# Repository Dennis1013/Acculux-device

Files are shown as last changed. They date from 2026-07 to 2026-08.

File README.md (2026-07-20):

# Acculux-device
**Capstone Project: Development of a Pressure and Navigation System For Nirscan Probe for Breast Cancer Detection**

The objective of this project is to add functionality to the existing NIR Imaging Inc. device in the way of:
 - Orientation tracking
 - Positional tracking
 - Force sensing

Download the latest software release here: https://github.com/jjhcwoo/Acculux-device/releases/latest

## Members

Justin Woo 

Allan Chang

Aodren Auffrédou-Heinicke

Dennis Huang

Nathan Cushing

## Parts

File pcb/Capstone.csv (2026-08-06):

Designator | Comment | Footprint | JLCPCB Part #
C1,C2 | 10u | Capacitor_SMD:C_0603_1608Metric
C5,C6,C7,C8,C10,C12,C13,C14,C15,C16,C18,C19,C20,C22,C23,C24,C26,C27,C28,C30,C34 | 0.1u | Capacitor_SMD:C_0603_1608Metric
C9 | 22u | Capacitor_SMD:C_0603_1608Metric
C11 | 1u | Capacitor_SMD:C_0603_1608Metric
C17,C21,C25,C29 | 47n | Capacitor_SMD:C_0603_1608Metric
C31,C35 | 2.2u +/- 10% X7R | Capacitor_SMD:C_0603_1608Metric
C32,C33 | 10n +/- 10% X7R | Capacitor_SMD:C_0603_1608Metric
C43,C44 | 10n | Capacitor_SMD:C_0603_1608Metric
D1 | D_Schottky BAT760 | Diode_SMD:D_SOD-323F
D2 | LED (RED) | LED_SMD:LED_0603_1608Metric
D3 | LED (AMBER) | LED_SMD:LED_0603_1608Metric
IC1,IC2,IC3,IC4 | HSFPAR004A | HSFPAR004A:HSFPAR004A | C470800
J1,J2,J3,J4 | Conn_01x01 | MountingHole:MountingHole_3.2mm_M3_DIN965_Pad
J5 | Conn_01x02 | Connector_PinHeader_2.54mm:PinHeader_1x04_P2.54mm_Horizontal
J6 | USB_C_Receptacle | Connector_USB:USB_C_Receptacle_GCT_USB4105-xx-A_16P_TopMnt_Horizontal
J7 | Conn_02x02_Counter_Clockwise | Connector_PinSocket_2.54mm:PinSocket_2x02_P2.54mm_Vertical
R1,R4,R9,R11,R12,R32,R33 | 10k | Resistor_SMD:R_0603_1608Metric
R2,R3 | 5.1k | Resistor_SMD:R_0603_1608Metric
R5,R16,R20,R24,R28 | 100 | Resistor_SMD:R_0603_1608Metric
R6 | 220 | Resistor_SMD:R_0603_1608Metric
R10 | 2k | Resistor_SMD:R_0603_1608Metric
R13,R17,R21,R25 | 6.49k +/- 1% | Resistor_SMD:R_0603_1608Metric
R14,R18,R22,R26 | 10k +/- 1% | Resistor_SMD:R_0603_1608Metric
R15,R19,R23,R27 | 3k +/- 1% | Resistor_SMD:R_0603_1608Metric
R36,R37,R38,R39 | 0 | Resistor_SMD:R_0603_1608Metric
SW1,SW2 | SW_Push | Button_Switch_SMD:SW_SPST_EVQP7A
U1,U7 | ADS1015IDGS | Package_SO:TSSOP-10_3x3mm_P0.5mm | C193969
U2 | ESP32-S3-WROOM-1 | RF_Module:ESP32-S3-WROOM-1 | C2913197
U3 | TLV75733PDBV | Package_TO_SOT_SMD:SOT-23-5 | C485517
U4 | USBLC6-2SC6 | Package_TO_SOT_SMD:SOT-23-6 | C7519
U6,U8,U9,U10 | INA333xxDGK | Package_SO:VSSOP-8_3x3mm_P0.65mm | C19450
U12,U13 | ICM-42688-P | ICM_42688_P:LGA14_2P5X3X0P91_TDK | C1850418

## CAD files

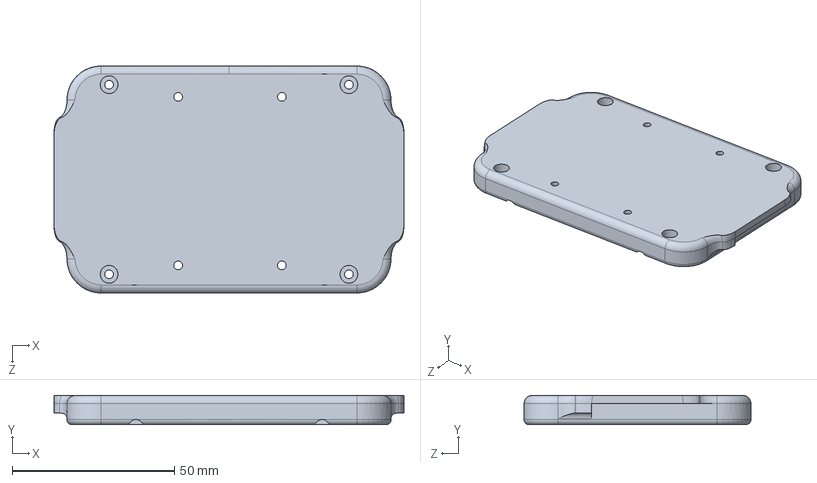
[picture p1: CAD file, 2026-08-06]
model/StampJacket.SLDPRT
108.0 x 9.00 x 70.0 mm

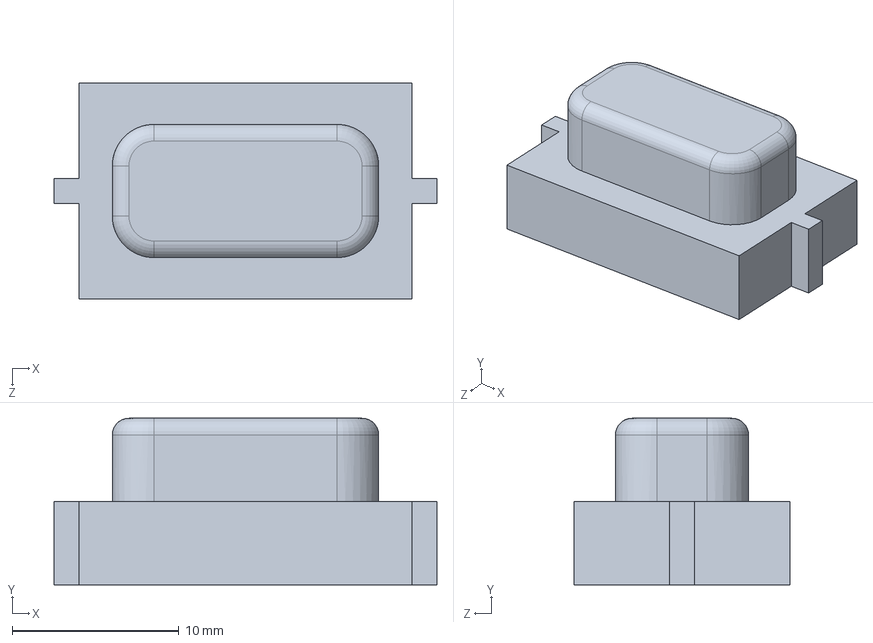
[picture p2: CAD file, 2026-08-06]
model/ScanButton.SLDPRT
23.0 x 10.0 x 13.0 mm

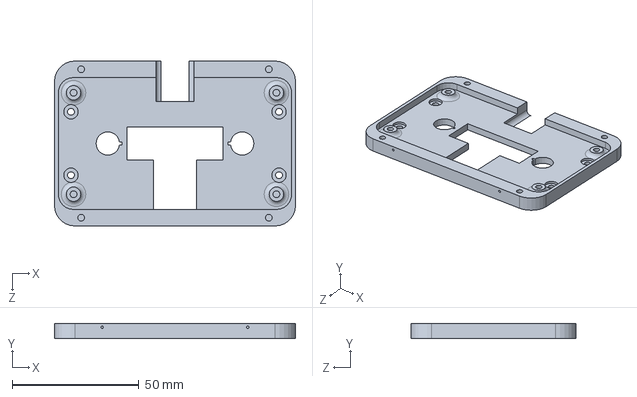
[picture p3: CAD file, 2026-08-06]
model/StampHead.SLDPRT
95.0 x 6.00 x 65.0 mm

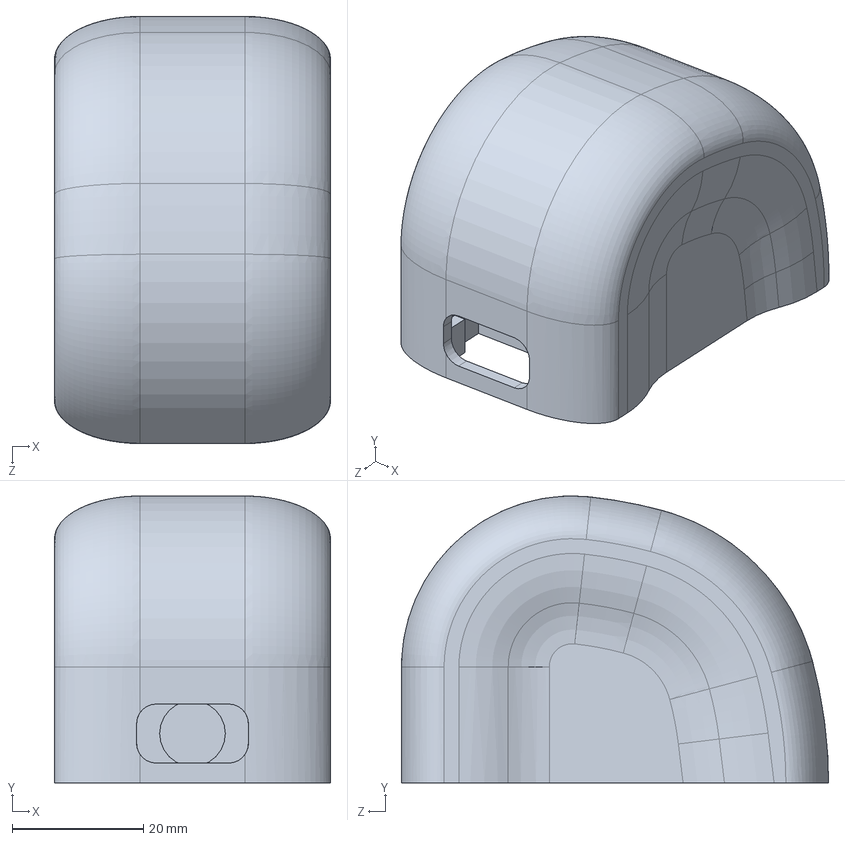
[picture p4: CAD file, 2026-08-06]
model/ErgoHandle.SLDPRT
42.0 x 43.6 x 65.0 mm

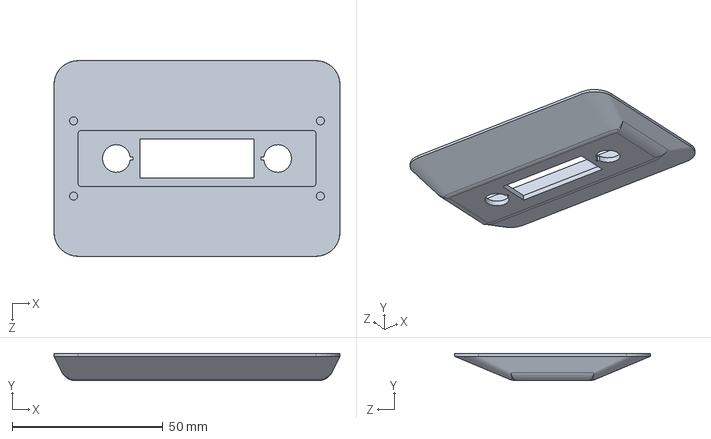
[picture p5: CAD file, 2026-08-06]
model/NIRscanhead.SLDPRT
95.0 x 9.05 x 65.0 mm

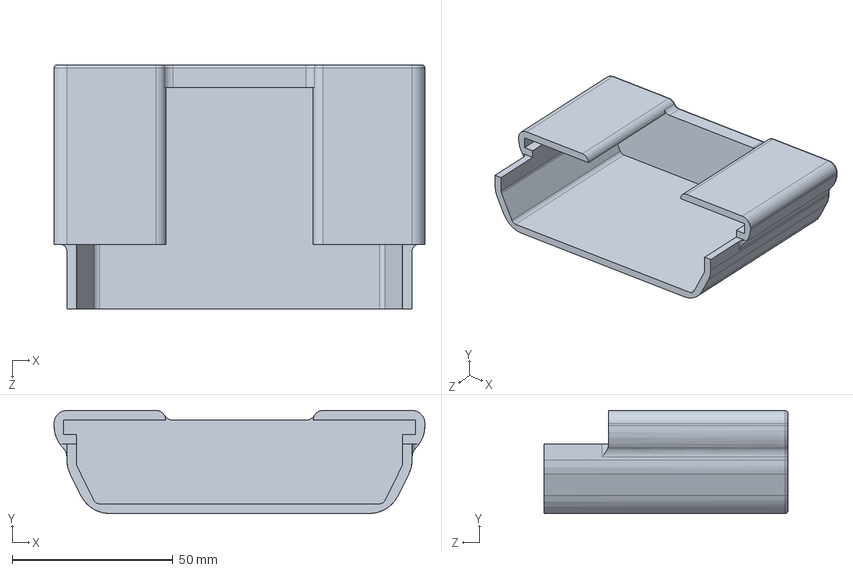
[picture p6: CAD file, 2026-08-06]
model/Cover.SLDPRT
115.4 x 32.0 x 76.0 mm

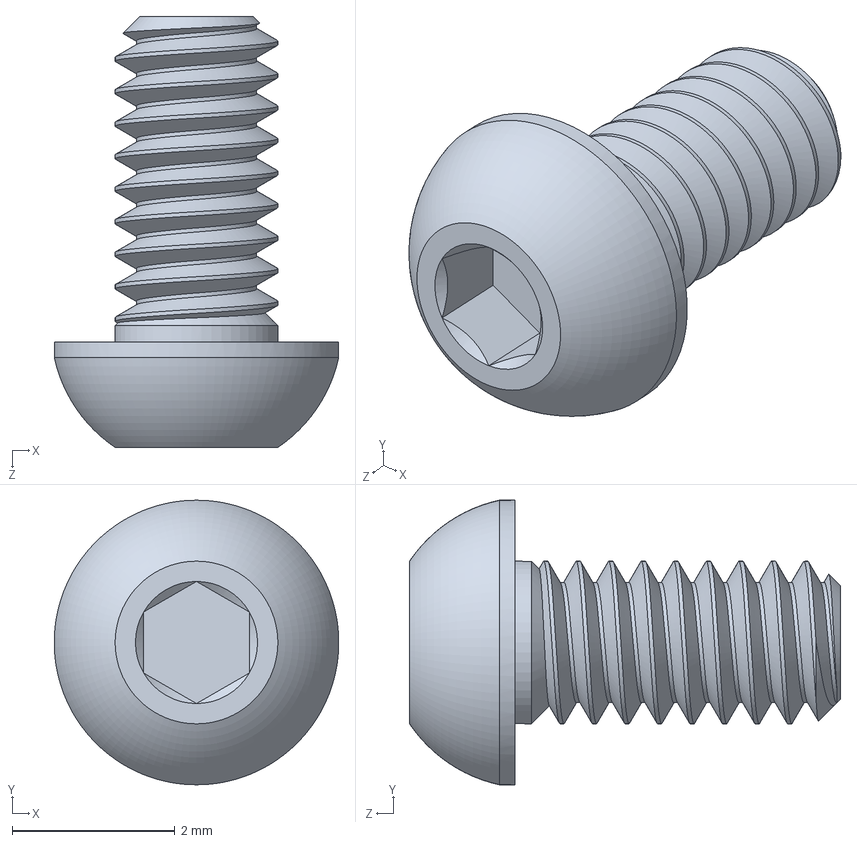
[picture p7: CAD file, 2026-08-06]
model/92095A451_18-8 Stainless Steel Button Head Hex-Drive Screw.SLDPRT
3.50 x 3.50 x 5.30 mm

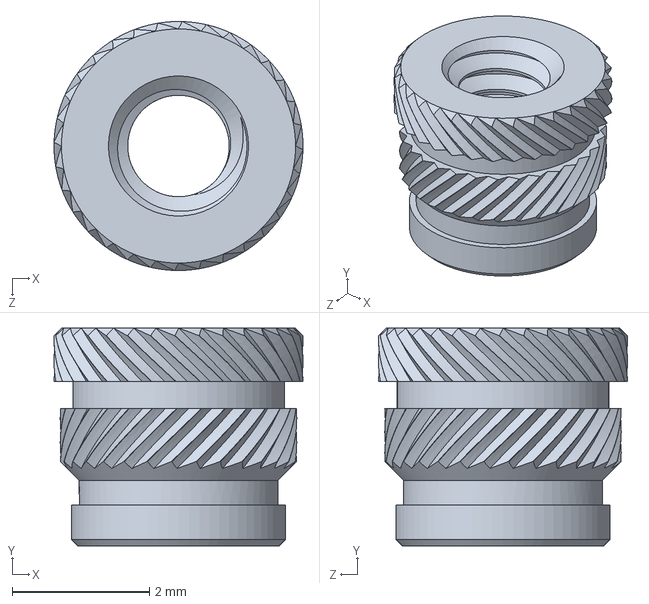
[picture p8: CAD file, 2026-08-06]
model/94459A767_Heat-Set Inserts for Plastic.SLDPRT
3.63 x 3.17 x 3.63 mm

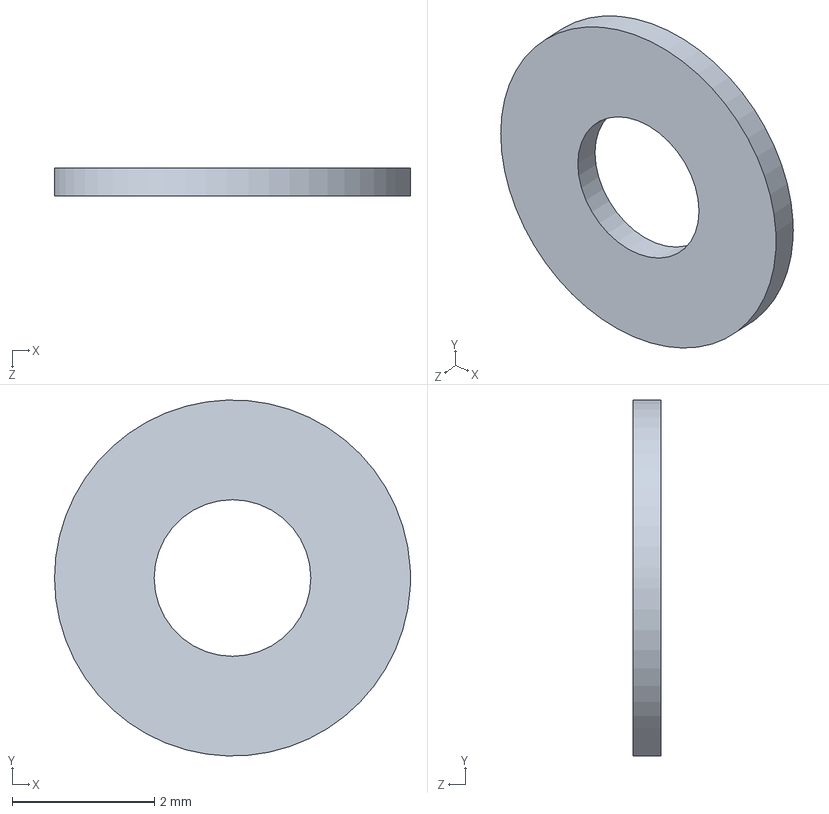
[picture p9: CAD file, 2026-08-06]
model/93475A195_18-8 Stainless Steel Washer.SLDPRT
5.00 x 5.00 x 0.4 mm

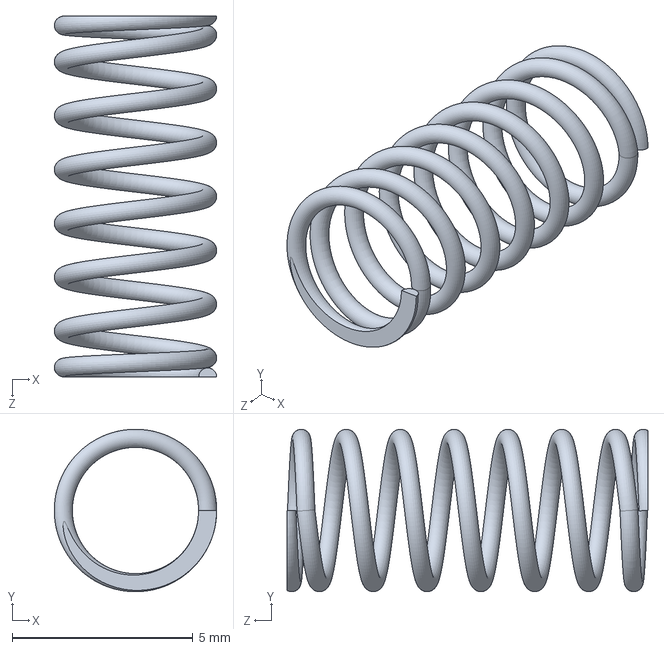
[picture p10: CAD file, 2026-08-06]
model/8969T382_316 Stainless Steel Corrosion-Resistant Compression Springs.SLDPRT
4.50 x 4.50 x 10.0 mm

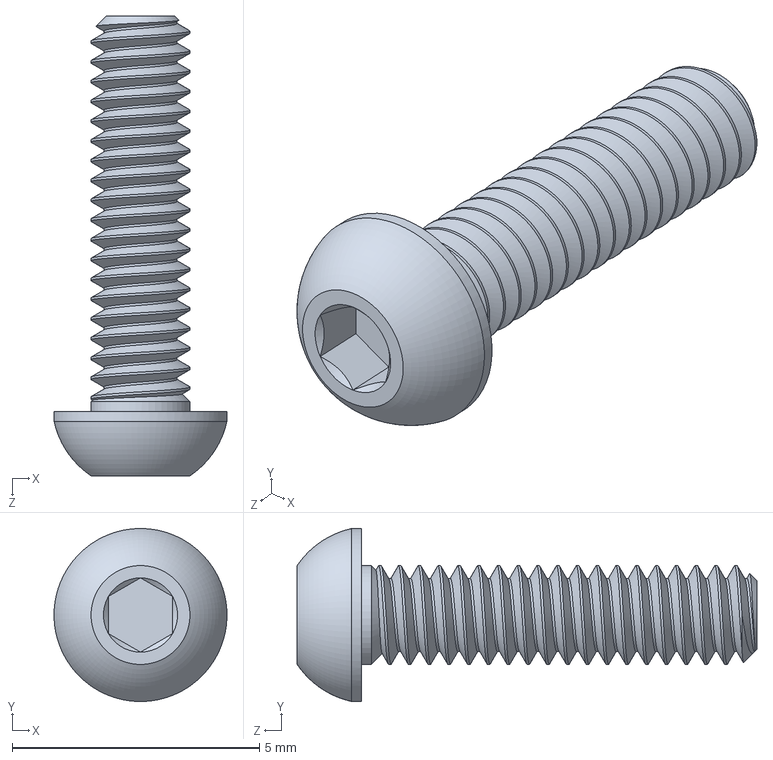
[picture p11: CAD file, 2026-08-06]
model/92095A454_18-8 Stainless Steel Button Head Hex-Drive Screw.SLDPRT
3.50 x 3.50 x 9.30 mm

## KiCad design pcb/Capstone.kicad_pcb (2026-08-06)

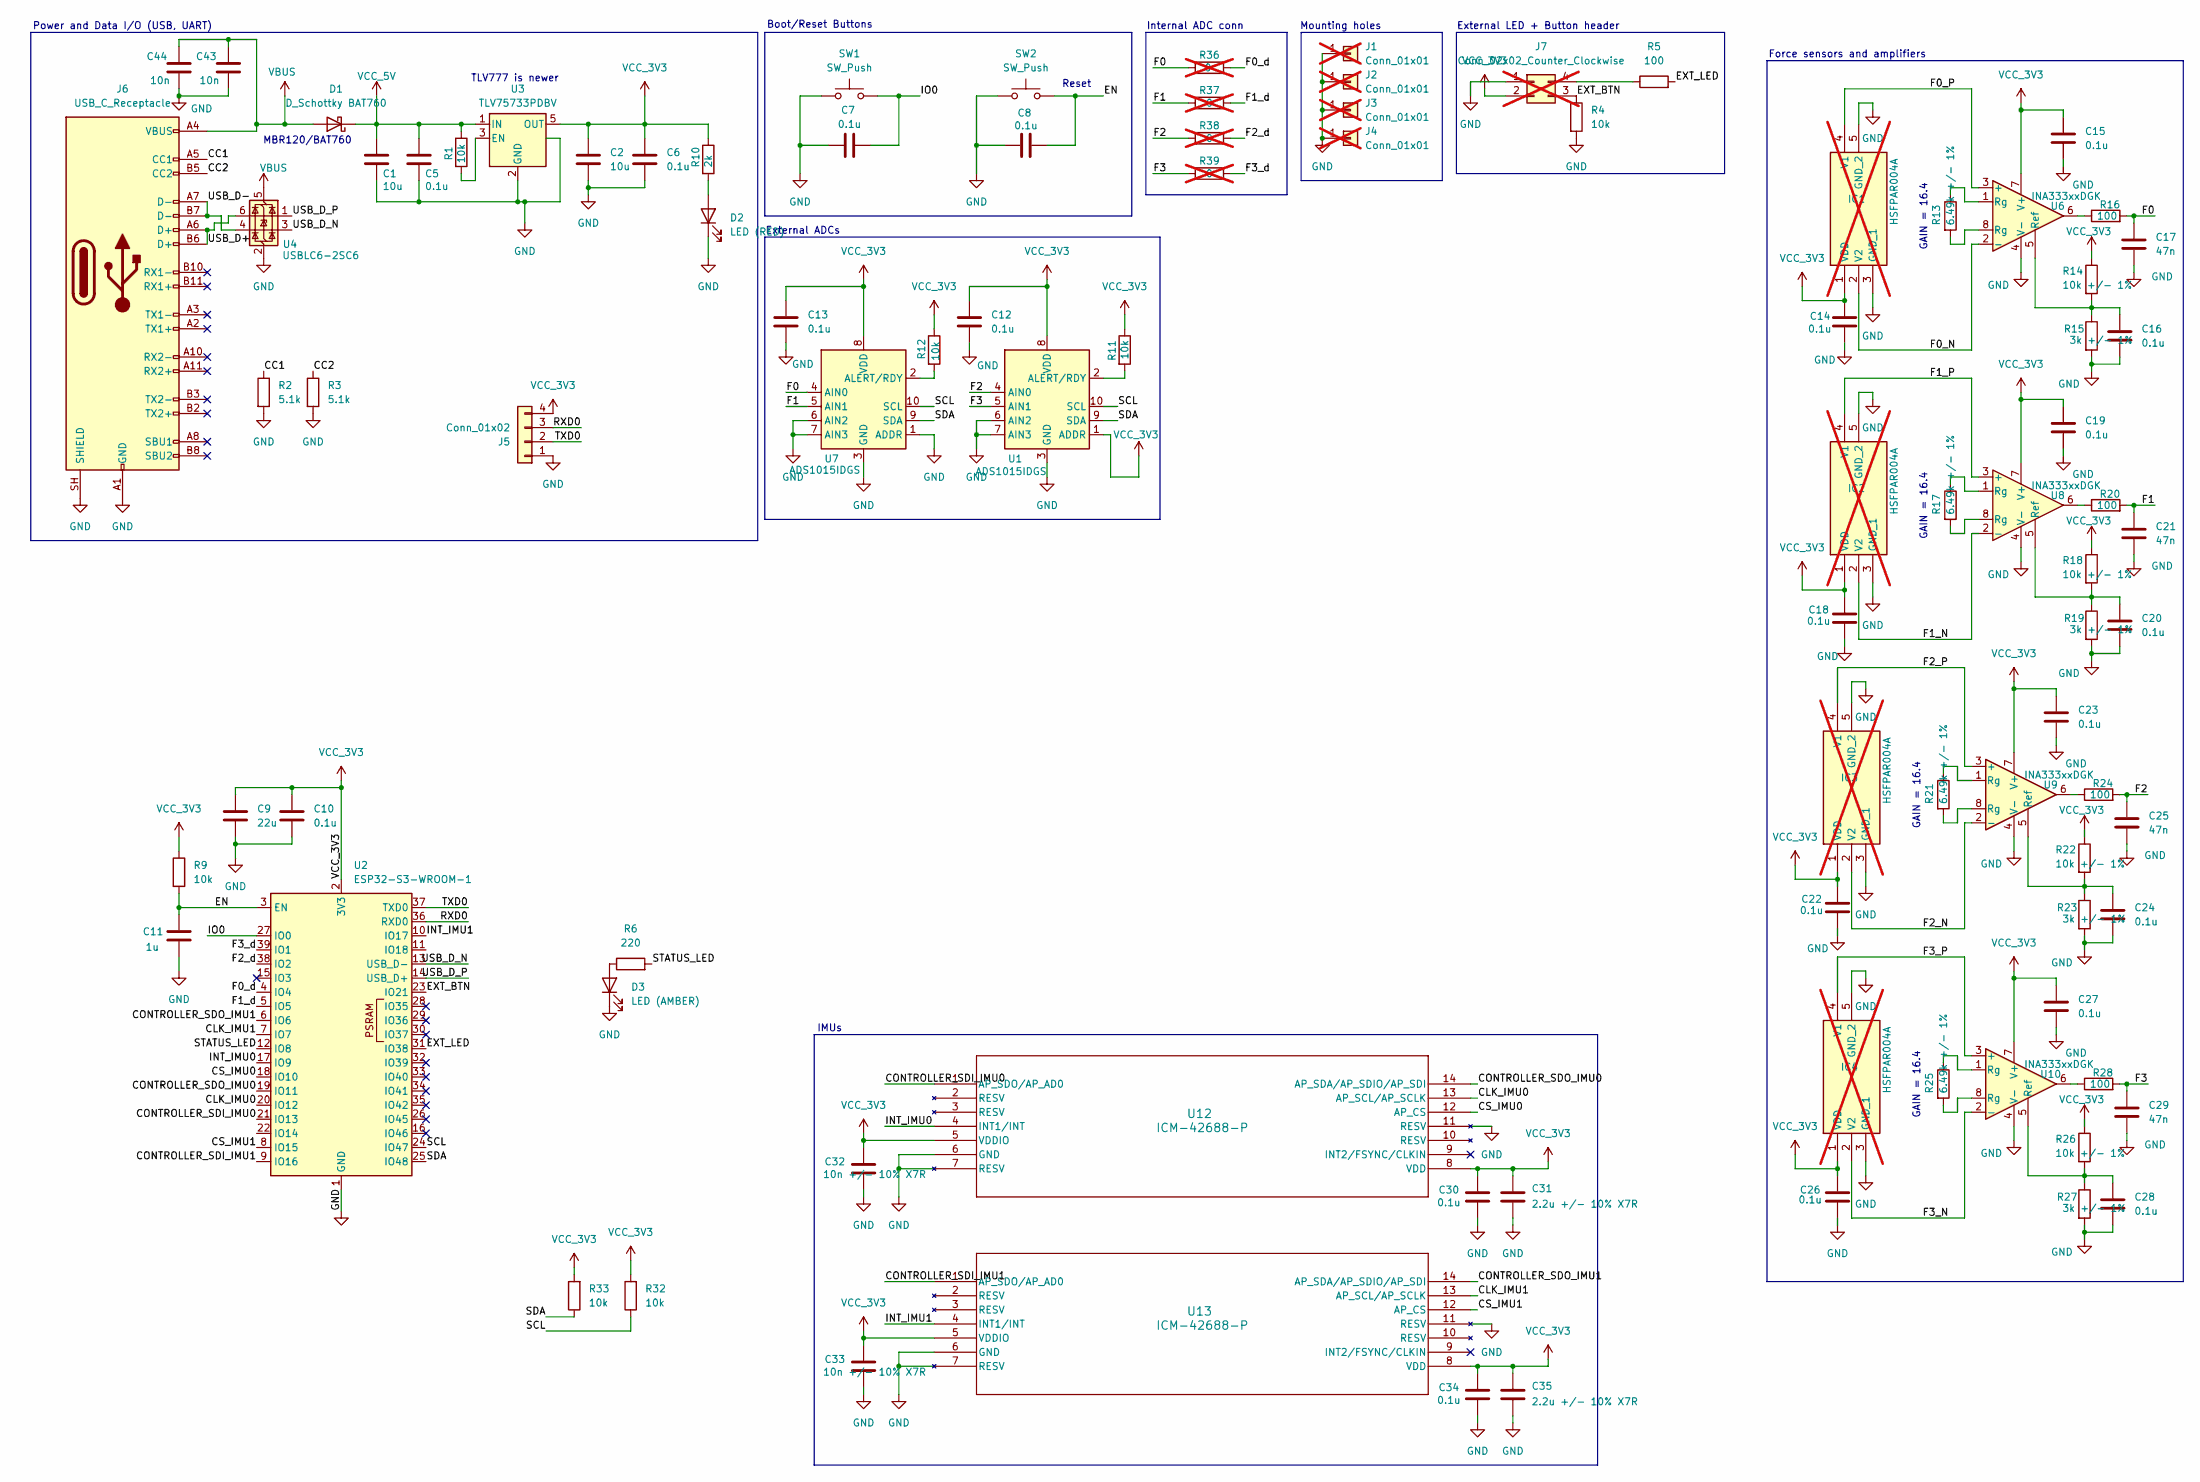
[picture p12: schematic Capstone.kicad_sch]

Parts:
C1, C2: 10u; C_0603_1608Metric
C5, C6, C7, C8, C10, C12, C13, C14, C15, C16, C18, C19, C20, C22, C23, C24, C26, C27, C28, C30, C34: 0.1u; C_0603_1608Metric
C9: 22u; C_0603_1608Metric
C11: 1u; C_0603_1608Metric
C17, C21, C25, C29: 47n; C_0603_1608Metric
C31, C35: 2.2u +/- 10% X7R; C_0603_1608Metric
C32, C33: 10n +/- 10% X7R; C_0603_1608Metric
C43, C44: 10n; C_0603_1608Metric
D1: D_Schottky BAT760; D_SOD-323F
D2: LED (RED); LED_0603_1608Metric
D3: LED (AMBER); LED_0603_1608Metric
IC1, IC2, IC3, IC4: HSFPAR004A; Manufacturer_Part_Number HSFPAR004A; Mouser Part Number 688-HSFPAR004A; not fitted
J1, J2, J3, J4: Conn_01x01; MountingHole_3.2mm_M3_DIN965_Pad; not fitted
J5: Conn_01x02; PinHeader_1x04_P2.54mm_Horizontal
J6: USB_C_Receptacle; USB_C_Receptacle_GCT_USB4105-xx-A_16P_TopMnt_Horizontal
J7: Conn_02x02_Counter_Clockwise; PinSocket_2x02_P2.54mm_Vertical; not fitted
R1, R4, R9, R11, R12, R32, R33: 10k; R_0603_1608Metric
R2, R3: 5.1k; R_0603_1608Metric
R5, R16, R20, R24, R28: 100; R_0603_1608Metric
R6: 220; R_0603_1608Metric
R10: 2k; R_0603_1608Metric
R13, R17, R21, R25: 6.49k +/- 1%; R_0603_1608Metric
R14, R18, R22, R26: 10k +/- 1%; R_0603_1608Metric
R15, R19, R23, R27: 3k +/- 1%; R_0603_1608Metric
R36, R37, R38, R39: 0; R_0603_1608Metric; not fitted
SW1, SW2: SW_Push; SW_SPST_EVQP7A
U1, U7: ADS1015IDGS; TSSOP-10_3x3mm_P0.5mm; Manufacturer_Part_Number ADS1015IDGSR; LCSC Part # C193969
U2: ESP32-S3-WROOM-1; Manufacturer_Part_Number ESP32-S3-WROOM-1-N4; LCSC Part # C2913197
U3: TLV75733PDBV; SOT-23-5; Manufacturer_Part_Number TLV75733PDBVR; LCSC Part # C485517
U4: USBLC6-2SC6; SOT-23-6; Manufacturer_Part_Number USBLC6-2SC6; LCSC Part # C7519
U6, U8, U9, U10: INA333xxDGK; VSSOP-8_3x3mm_P0.65mm; Manufacturer_Part_Number INA333AIDGKR; LCSC Part # C19450
U12, U13: ICM-42688-P; LGA14_2P5X3X0P91_TDK; Manufacturer_Part_Number ICM-42688-P; LCSC Part # C1850418

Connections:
/CC1: J6.A5 (CC1), R2.1
/CC2: J6.B5 (CC2), R3.1
/CLK_IMU0: U2.20 (IO12), U12.13 (AP_SCL/AP_SCLK)
/CLK_IMU1: U2.7 (IO7), U13.13 (AP_SCL/AP_SCLK)
/CONTROLLER_SDI_IMU0: U2.21 (IO13), U12.1 (AP_SDO/AP_AD0)
/CONTROLLER_SDI_IMU1: U2.9 (IO16), U13.1 (AP_SDO/AP_AD0)
/CONTROLLER_SDO_IMU0: U2.19 (IO11), U12.14 (AP_SDA/AP_SDIO/AP_SDI)
/CONTROLLER_SDO_IMU1: U2.6 (IO6), U13.14 (AP_SDA/AP_SDIO/AP_SDI)
/CS_IMU0: U2.18 (IO10), U12.12 (AP_CS)
/CS_IMU1: U2.8 (IO15), U13.12 (AP_CS)
/EN: C8.2, C11.1, R9.2, SW2.2, U2.3 (EN)
/EXT_BTN: J7.3, R4.1, U2.23 (IO21)
/EXT_LED: R5.2, U2.31 (IO38)
/F0: C17.1, R16.2, R36.2, U7.4 (AIN0)
/F0_N: IC1.2 (V2), U6.2 (-)
/F0_P: IC1.4 (V1), U6.3 (+)
/F0_d: R36.1, U2.4 (IO4)
/F1: C21.1, R20.2, R37.2, U7.5 (AIN1)
/F1_N: IC2.2 (V2), U8.2 (-)
/F1_P: IC2.4 (V1), U8.3 (+)
/F1_d: R37.1, U2.5 (IO5)
/F2: C25.1, R24.2, R38.2, U1.4 (AIN0)
/F2_N: IC3.2 (V2), U9.2 (-)
/F2_P: IC3.4 (V1), U9.3 (+)
/F2_d: R38.1, U2.38 (IO2)
/F3: C29.1, R28.2, R39.2, U1.5 (AIN1)
/F3_N: IC4.2 (V2), U10.2 (-)
/F3_P: IC4.4 (V1), U10.3 (+)
/F3_d: R39.1, U2.39 (IO1)
/INT_IMU0: U2.17 (IO9), U12.4 (INT1/INT)
/INT_IMU1: U2.10 (IO17), U13.4 (INT1/INT)
/IO0: C7.2, SW1.2, U2.27 (IO0)
/RXD0: J5.3, U2.36 (RXD0)
/SCL: R32.1, U1.10 (SCL), U2.24 (IO47), U7.10 (SCL)
/SDA: R33.1, U1.9 (SDA), U2.25 (IO48), U7.9 (SDA)
/STATUS_LED: R6.2, U2.12 (IO8)
/TXD0: J5.2, U2.37 (TXD0)
/USB_D+: J6.A6 (D+), J6.B6 (D+), U4.6 (I/O1)
/USB_D-: J6.A7 (D-), J6.B7 (D-), U4.4 (I/O2)
/USB_D_N: U2.13 (USB_D-), U4.3 (I/O2)
/USB_D_P: U2.14 (USB_D+), U4.1 (I/O1)
GND: C1.2, C2.2, C5.2, C6.2, C7.1, C8.1, C9.2, C10.2, C11.2, C12.2, C13.2, C14.2, C15.2, C16.2, C17.2, C18.2, C19.2, C20.2, C21.2, C22.2, C23.2, C24.2, C25.2, C26.2, C27.2, C28.2, C29.2, C30.2, C31.2, C32.2, C33.2, C34.2, C35.2, C43.2, C44.2, D2.1 (K), D3.1 (K), IC1.3 (GND_1), IC1.5 (GND_2), IC2.3 (GND_1), IC2.5 (GND_2), IC3.3 (GND_1), IC3.5 (GND_2), IC4.3 (GND_1), IC4.5 (GND_2), J1.1 (Pin_1_1), J2.1 (Pin_1_1), J3.1 (Pin_1_1), J4.1 (Pin_1_1), J5.1, J6.A1 (GND), J6.A12 (GND), J6.B1 (GND), J6.B12 (GND), J6.SH (SHIELD), J7.1, R2.2, R3.2, R4.2, R15.2, R19.2, R23.2, R27.2, SW1.1, SW2.1, U1.3 (GND), U1.6 (AIN2), U1.7 (AIN3), U2.1 (GND), U2.40 (GND), U2.41 (GND), U3.2 (GND), U3.4 (NC), U4.2 (GND), U6.4 (V-), U7.1 (ADDR), U7.3 (GND), U7.6 (AIN2), U7.7 (AIN3), U8.4 (V-), U9.4 (V-), U10.4 (V-), U12.6 (GND), U12.7 (RESV), U12.11 (RESV), U13.6 (GND), U13.7 (RESV), U13.11 (RESV)
unnamed: D2.2 (A), R10.2
unnamed: D3.2 (A), R6.1
unnamed: J7.4, R5.1
unnamed: R13.1, U6.1 (Rg)
unnamed: R13.2, U6.8 (Rg)
unnamed: R16.1, U6.6
unnamed: R17.1, U8.1 (Rg)
unnamed: R17.2, U8.8 (Rg)
unnamed: R20.1, U8.6
unnamed: R21.1, U9.1 (Rg)
unnamed: R21.2, U9.8 (Rg)
unnamed: R24.1, U9.6
unnamed: R25.1, U10.1 (Rg)
unnamed: R25.2, U10.8 (Rg)
unnamed: R28.1, U10.6
unnamed: R11.2, U1.2 (ALERT/RDY)
unnamed: R1.2, U3.3 (EN)
unnamed: C16.1, R14.2, R15.1, U6.5 (Ref)
unnamed: R12.2, U7.2 (ALERT/RDY)
unnamed: C20.1, R18.2, R19.1, U8.5 (Ref)
unnamed: C24.1, R22.2, R23.1, U9.5 (Ref)
unnamed: C28.1, R26.2, R27.1, U10.5 (Ref)
VBUS: C43.1, C44.1, D1.2 (A), J6.A4 (VBUS), J6.A9 (VBUS), J6.B4 (VBUS), J6.B9 (VBUS), U4.5 (VBUS)
VCC_3V3: C2.1, C6.1, C9.1, C10.1, C12.1, C13.1, C14.1, C15.1, C18.1, C19.1, C22.1, C23.1, C26.1, C27.1, C30.1, C31.1, C32.1, C33.1, C34.1, C35.1, IC1.1 (VDD), IC2.1 (VDD), IC3.1 (VDD), IC4.1 (VDD), J5.4, J7.2, R9.1, R10.1, R11.1, R12.1, R14.1, R18.1, R22.1, R26.1, R32.2, R33.2, U1.1 (ADDR), U1.8 (VDD), U2.2 (3V3), U3.5 (OUT), U6.7 (V+), U7.8 (VDD), U8.7 (V+), U9.7 (V+), U10.7 (V+), U12.5 (VDDIO), U12.8 (VDD), U13.5 (VDDIO), U13.8 (VDD)
VCC_5V: C1.1, C5.1, D1.1 (K), R1.1, U3.1 (IN)

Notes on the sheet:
Internal ADC conn
External ADCs
Force sensors and amplifiers
GAIN = 16.4
IMUs
MBR120/BAT760
TLV777 is newer
Boot/Reset Buttons
Reset
External LED + Button header
Power and Data I/O (USB, UART)
Mounting holes

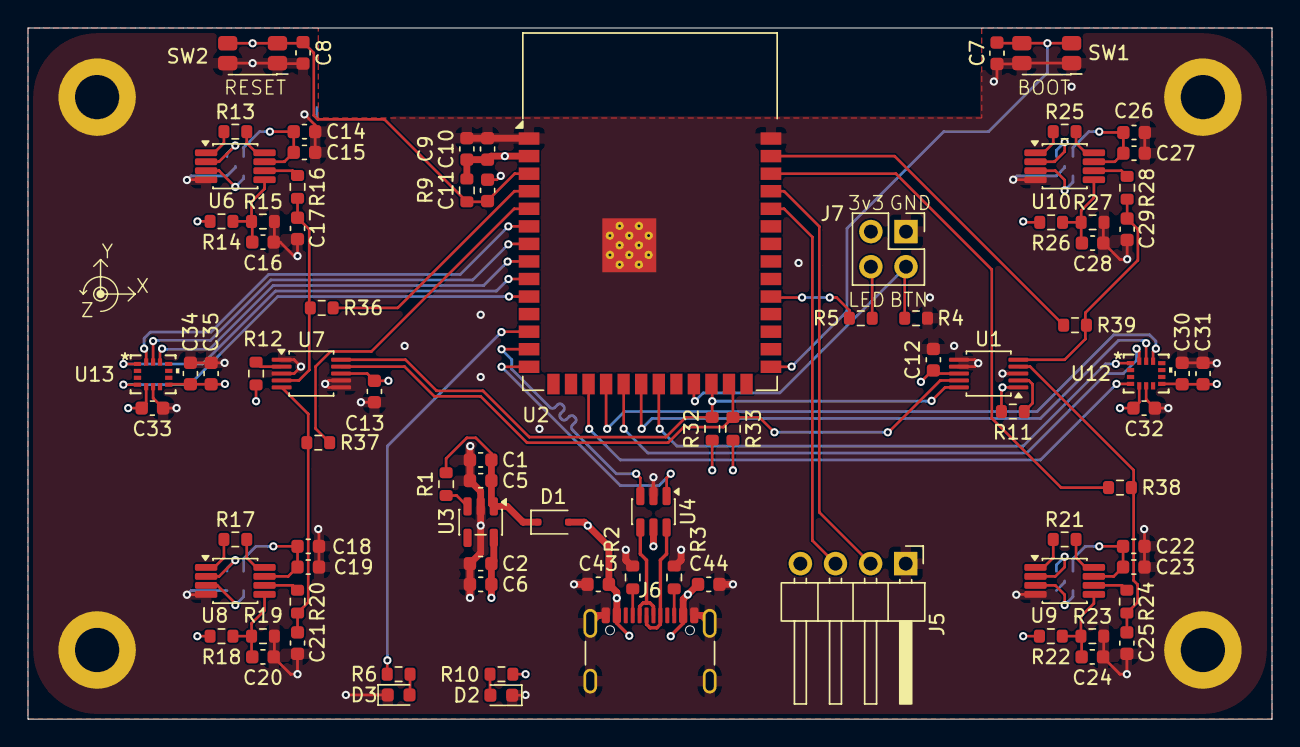
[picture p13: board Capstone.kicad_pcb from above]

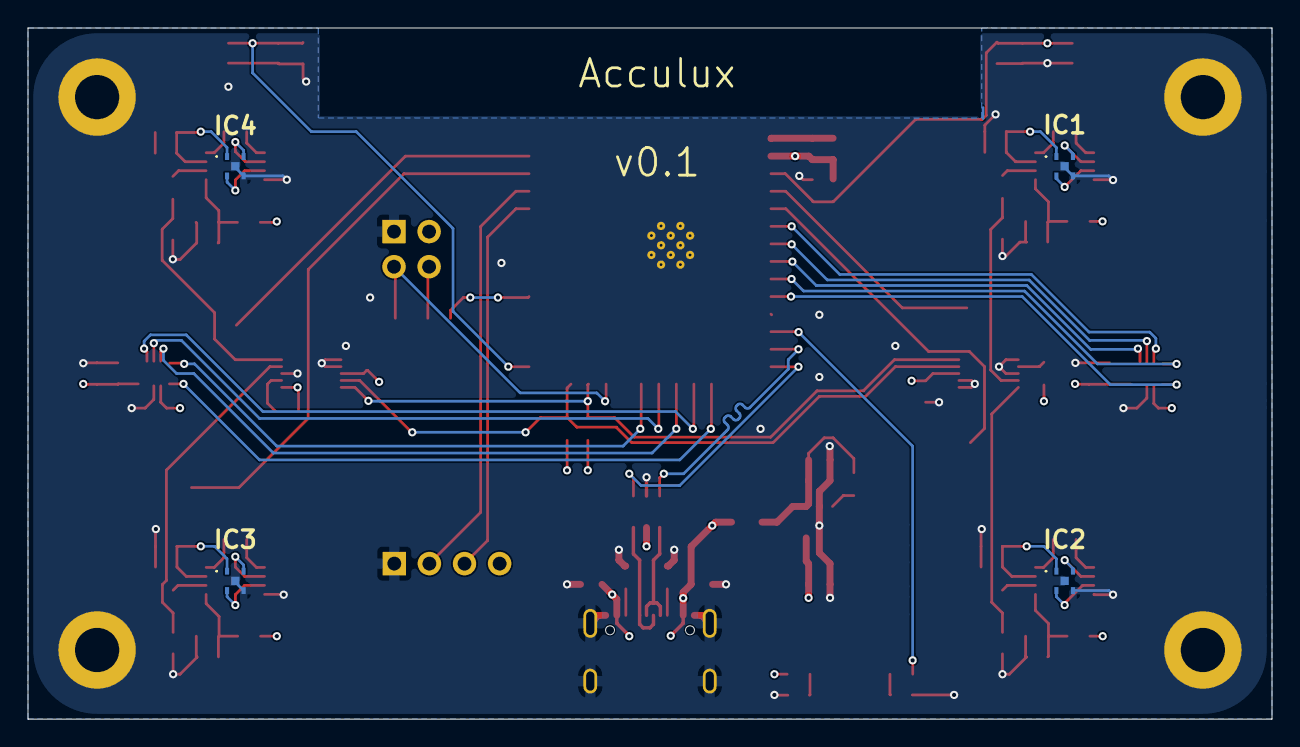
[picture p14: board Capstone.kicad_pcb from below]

Board: 4 copper layers, 90.0 x 50.0 mm, 94 parts (4 on the bottom side), 67 nets.

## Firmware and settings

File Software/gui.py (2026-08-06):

import sys
import numpy as np
import csv
import pyqtgraph.opengl as gl
from PyQt6.QtCore import QSize, Qt, QTimer
from PyQt6.QtWidgets import QApplication, QGridLayout, QHBoxLayout, QMainWindow, QPushButton, QWidget, QVBoxLayout, QGroupBox, QFormLayout, QLabel, QMessageBox, QCheckBox
from PyQt6.QtGui import QFont

font = QFont()
font.setPointSize(12)
buttonFont = QFont()
buttonFont.setPointSize(14)

# Subclass QMainWindow to customize your application's main window
class MainWindow(QMainWindow):
    def __init__(self):
        super().__init__()
        self.latest_position = np.zeros(3)
        self.latest_angles = np.zeros(3)
        self.latest_force = 0.0
        self.current_popup = None
        self.scan_data = [] # For recording data

        self.scanning = False
        self.reset_request = False

        self.scan_timer = QTimer(self)
        self.scan_timer.setSingleShot(True)
        self.scan_timer.timeout.connect(self.stop_scan)

        self.timer = QTimer()
        self.timer.timeout.connect(self.update_sensor_display)
        self.timer.start(100)

        self.setWindowTitle("Acculux")

        layout = QVBoxLayout()

        self.plot3D = PyQtGraph3DWindow()
        layout.addWidget(self.plot3D, stretch=50)

        self.bottom = bottomWindow()
        self.bottom.scanButton.clicked.connect(self.start_scan)
        self.bottom.saveButton.clicked.connect(self.save_scan)
        layout.addWidget(self.bottom)

        widget = QWidget()
        widget.setLayout(layout)
        self.setCentralWidget(widget)

    def update_sensor_display(self):
        roll, pitch, yaw = self.latest_angles
        x, y, z = self.latest_position
        force = self.latest_force

        self.bottom.sensorPanel.update_angles(
            roll,
            pitch,
            yaw
        )

        self.bottom.sensorPanel.update_position(
            x,
            y,
            z
        )

        self.bottom.sensorPanel.update_force(
            force
        )
        # Records data if user ticks the checkbox
        if self.bottom.recordCheckBox.isChecked():
            self.scan_data.append([x, y, z, 
                                   roll, pitch, yaw, 
                                   force]) 

    def update_connection_status(self, connected):
        if connected:
            self.bottom.statusLight.setStyleSheet(
                "background-color: green; border-radius: 15px; border: 2px solid black;"
            )
                    
        else:
            self.bottom.statusLight.setStyleSheet(
                "background-color: red; border-radius: 15px; border: 2px solid black;"
            )

    def start_scan(self):

        # Ignore if already scanning
        if self.scanning:
            return

        print("Scan started")
        self.reset_request = True
        self.scanning = True

        # Run for 5 seconds
        self.scan_timer.start(5000)

    def stop_scan(self):

        print("Scan finished")

        self.scanning = False

    def show_status_popup(self, message):
        # Close existing popup
        if self.current_popup is not None:
            self.current_popup.close()
            self.current_popup = None
        popup = QMessageBox(self)
        popup.setWindowTitle("Status")
        popup.setText(message)
        popup.setIcon(QMessageBox.Icon.Information)
        popup.show()
        self.current_popup = popup

    def save_scan(self):
        headers = ["X", "Y", "Z", "Roll", "Pitch", "Yaw", "Force"] 

        if not self.scan_data:
            dlg = QMessageBox(self)
            dlg.setWindowTitle("Error")
            dlg.setText("No Data To Export")
            dlg.exec()
            return  
            
        with open("output.csv", "w", newline="") as file:
            writer = csv.writer(file)
            writer.writerow(headers) # Write headers
            writer.writerows(self.scan_data) # Write data

            dlg = QMessageBox(self)
            dlg.setWindowTitle("Saved")
            dlg.setText("Data successfully exported")
            dlg.exec()        

class bottomWindow(QWidget):
    def __init__(self):
        super().__init__()
        self.setFont(font)
        layout = QHBoxLayout(self)

        self.statusLight = QLabel()
        self.statusLight.setFixedSize(30, 30)
        self.statusLight.setStyleSheet("""
        background-color: red;
        border-radius: 15px;
        border: 2px solid black;
    """)
        self.connectedLabel = QLabel("Connected:")
        self.connectedLabel.setFont(buttonFont)
        layout.addWidget(self.connectedLabel)
        layout.addWidget(self.statusLight)
        self.calibrateButton = QPushButton("Calibrate")
        self.calibrateButton.setStyleSheet("""
            QPushButton {
                background-color: blue;
                color: white;
                font-size: 24px;
                border: 2px solid black;                       
            }
        """)
        self.calibrateButton.setFixedSize(250, 100)
        # self.calibrateButton.clicked.connect(self.calibrate) 
        layout.addWidget(self.calibrateButton)

        self.scanButton = QPushButton("Scan")
        self.scanButton.setStyleSheet("""
            QPushButton {
                background-color: orange;
                color: black;
                font-size: 24px;
                border: 2px solid black;                       
            }
        """)
        self.scanButton.setFixedSize(250, 100)
        # self.scanButton.clicked.connect(self.scan) 
        layout.addWidget(self.scanButton)

        self.saveButton = QPushButton("Save")
        self.saveButton.setStyleSheet("""
            QPushButton {
                background-color: green;
                color: black;
                font-size: 24px;
                border: 2px solid black;                       
            }
        """)
        self.saveButton.setFixedSize(250, 100)
        # self.saveButton.clicked.connect(self.save)
        layout.addWidget(self.saveButton)

        self.sensorPanel = SensorPanel()
        layout.addWidget(self.sensorPanel, stretch=2)

        self.recordCheckBox = QCheckBox("Record Data", self)
        self.recordCheckBox.setChecked(False) 
        layout.addWidget(self.recordCheckBox)
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

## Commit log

2026-07-20 Initial commit
    GUI for Acculux device
2026-07-30 Add algorithms for software
    - Add simulated IMU data
    - Add calibration mechanism
    - Add preliminary ESKF with quaternion
2026-07-30 Simulate physical IMU data
    - Fix bias and calibration mechanism
    - Revise GUI to automatically update from data
    - Implement button action
    - Add sensor data for testing in csv file
    [Data.csv]
2026-07-30 Implementation of real-time reading of probe.
2026-07-30 Add functionality to ESKF
    - Add covariance prediction
    - Add surface constraint
    - Add velocity constraint
    - Fix crashing due to corrupt serial data
    [gui.py, main.py]
2026-07-30 Add force sensing and GUI functionality
    - Calibration trigger through calibrate button with popups
    - Scan trigger through scan button
    - Add force calibration and readings
    - Connected button detects probe
    - Automatically detect COM port
    - Clean up unused files
    [Data.csv]
2026-08-04 Add preliminary device prototype
    Initial plate and spring mechanism for force sensing. Used as a proof-of-concept.
    [Head.SLDPRT, Probe.SLDASM, ProbeRecreate.SLDPRT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]
2026-08-04 Revise plate and spring design
    Refine probe head plate and body mechanism
    [Assembly.SLDASM, Body.SLDPRT, Head.SLDPRT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]
2026-08-04 Revise to jacket design
    Pivot to jacket design. Preliminary proof-of-concept for jacket mechanism for force sensing resistors.
    [Assembly.SLDASM, Body.SLDPRT, Head.SLDPRT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]
2026-08-04 Revise jacket protoype
    - Refine jacket design
    - Add model for force sensing resistor
    [Assembly.SLDASM, OhmiteFSR05.SLDPRT, Stamp Head.SLDPRT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]
2026-08-06 Revise jacket prototype
    Shave down handle for compact design. Design will now incorporate MEMS-based force sensors rather than force sensing resistors.
    [Assembly.SLDASM, JacketAssembly.SLDASM, OhmiteFSR05.SLDPRT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]
2026-08-06 Add initial PCB layout
    Preliminary printed circuit board layout with selected components.
    [Capstone.kicad_pcb, Capstone.kicad_sch]
2026-08-06 Connect components on PCB
    Add electronic connections for printed circuit board components.
    [Capstone.kicad_pcb, Capstone.kicad_sch]
2026-08-06 Revise model to fit PCB
    - Add PCB into SolidWorks model
    - Adjust model to allow for electronics
    [StampHead.SLDPRT, StampJacket.SLDPRT]
2026-08-06 Revise PCB for procurement
    Revise printed circuit board with feedback from industry sponsor. Final design to send to JLCPCB.
    - Add Gerber files
    - Add Component Placement List and position files
    [Capstone-B_Cu.gbr, Capstone-B_Mask.gbr, Capstone-B_Paste.gbr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]
2026-08-06 Add final device model design
    Finalize model in SolidWorks. Files will be used for 3D printing and physical assembly.
    [8969T382_316 Stainless Steel Corrosion-Resistant Compression Springs.SLDPRT, 92095A451_18-8 Stainless Steel Button Head Hex-Drive Screw.SLDPRT, 92095A454_18-8 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]
2026-08-06 Added 'save' button to GUI
